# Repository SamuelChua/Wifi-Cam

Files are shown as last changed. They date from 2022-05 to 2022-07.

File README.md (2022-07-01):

# Building a 'Wifi-Seeing' Camera

## Description

In this project, I used a software defined radio (SDR) along with a directional Yagi antenna to scan and detect Wifi signals, overlaying it on top of a normal camera
image in order to give directional information of signal sources (possibly through
walls!). Overall, I controlled and manipulated both the radio and camera with DSP and arduino control of a servo motor for the antenna. With this application, I'm able to display the spatial awareness of Wifi signals. 

WhatsApp Image 2022-06-30 at 9 37 27 AM (1)

## Table of Contents 
- Hardware/Software Tools used
- Programs/Files
- Running the program
- Video Demonstration
- Ideas I experimented with along the way
- Concluding Remarks 

## Hardware/Software Tools Used
### USRP Software Defined Radio 
The USRP B205 Mini-i is a SDR designed by Ettus Research which has a Frequency range: 70 MHz – 6 GHz and up to 56 MHz of instantaneous Bandwidth. Using SDR technologies can allow me to easily configure to the requirements I'm looking to detect Wifi signals


### Yagi Antenna
The 2.4GHz Yagi Antenna is a directional antenna which has a good front-to-back ratio of 16dB to minimise unwanted signals. 


Here are some links to the datasheet of the antenna 

https://www.farnell.com/datasheets/1580319.pdf

### Servo Motor
Despite its small size, the servo motor has a peak stall torque of 1.5kg.cm which is sufficient to rotate the antenna (300g) given certain support of the antenna. Similarly, here are some links to the datasheet of the servo motor

https://sg.element14.com/multicomp-pro/mp-708-0001/servo-motor-180deg/dp/3359813?CMP=i-55c5-00001621
https://www.farnell.com/datasheets/2914226.pdf

### GNURadio 
GNU Radio is a free & open-source software development toolkit that provides signal processing blocks to implement software radios. I ran it mainly with Python 

GNURadio was installed via http://www.gcndevelopment.com/gnuradio/downloads.htm on Windows, specifically GNURadio V3.8.2.0-win64 for my project. 

### Arduino
Arduino is an open-source tool for electronics projects which consists of the microcontroller and an IDE to run and upload code to the physical Arduino code. 

### Reimage Package

Credits to my mentor, Gabriel. I can save the trouble of repeatedly running np.abs(d) and the lag to generate a graph
https://github.com/icyveins7/reimage

## Programs/Files
Webcam
- Controlling the USB Webcam

Arduino
- Will send Arduino list of angles via serial communication from Python to Arduino

Master
- Master Program to control the GNURadio, Arduino and Webcam 

Extract
- GNURadio generated script with additional new_main function to access GNURadio 'locally'

Pano
- Generate panorama from the photos taken by webcam

Read_filename
- Data processing of bin file generated from GNURadio to give final heatmap of relative power from Wifi signals + overlaying picture of surrounding

Vert_Hori
- Arduino code to accept the list of angles from Arduino.py, and move the servos to control the vertical and horizontal movement of the antenna via serial communication between Python and Arduino

Sweep/Servo Motor
- Arduino test code to ensure that the servo is working 

Reimage package
- To visualise recorded RF data in IQ samples

3D Prints
- STL and SCAD files for 3D printing
- Infill Density 30-50% depending on application (how dense is the print)
- Made use of MakerBot.Print/GrabCAD Print (Using UPrint SE Plus/Industry Printer in DSO Playground of which those with PRINT extension used GrabCAD Print)

## Running the program
After installing GNURadio, ensure the connnections are made between the servo and Arduino and USRP is plugged into your device. Run master.py in GNURadio command line with the extract.py in the same directory and let the fun begin! 



### GNURadio Flowgraph

There are 2 routes you can use the flowchart

1. Muting the signal via a "Switch" (Used in this project)
By making use GT GUI Chooser with my Multiply Const block, I can change the value of the constant in the GNURadio interacing when running the script, just muting the USRP source by a flick of a switch. 



2. Timed Intervals 
Created a custom embedded python block to record for n seconds then mute the USRP signal for n seconds. The cycle will then continue



### Arduino (Vert_Hori)

The code is designed to split the string of angles arduino.py sends into its horizontal & vertical components and having map the speed to control the movement of the servo 

### read_filename

Below is the illustration of how the mean power values are calculated 
Screenshot 2022-05-19 113415 png-mh

## Video Demonstration

Refer to https://youtu.be/VoVrBwUprhU

## Ideas I experimented with along the way: 

### GNURadio
#### Generating the output bin file:
- Using a selector block and n file sinks as output (Able to get 6 separate readings in 6 bin files but limitation was the version I was using couldn't update to latest selector block with input and output index to swap between different output indices. Additionally, having n sinks to give n separate readings wouldn't be sustainable to keep adding file sink blocks in GNURadio)



- Using custom python blocks to swap sinks (Swap File Sink & Custom File Sink)
Couldn't come to fruition, nonetheless might need more than 1 file sink as it may not be possible to reuse the same file sink after swapping to null sink
Note that Custom File Sink is a Hier Block




- Getting the GNURadio to record the data using stream tags (stream.grc/tagged file sink.grc). Had trouble to generate tags and getting the flowchart to recognise these tags/bursts to switch the on/off record 

- Getting timed recordings using the 'head' block in GNURadio(extract_nogui.grc). It did work to an extent, as it will turn off the USRP afterwards and not knowing how it can turn on again

## Concluding Remarks 
I thoroughly enjoyed the entire process of figuring out how open source frameworks like GNURadio and Arduino work, building my own 'WiFi-seeing' camera from scratch independently. I'm most certainly looking forward to exploiting more technologies that touch both hardware and software. Feel free to reach out for any questions!

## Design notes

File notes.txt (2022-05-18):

MasterScript.py

--- multiprocess call gnuradioscript.py (default off)

open gnuradioscript, webcam, arduino (current progress)		

start while 1:
	master tell arduino.py to send one command
	arduino.py (send one command to arduino)
	arduino move (send msg to master that it's done)
	master send command to webcam to take pic and gnuradio to record for 5s
	webcam take pic, multiprocess turn on gnuradio 
	multiprocess turn off gnuradio (send msg to master that it's done)
	master tell arduino.py to send next command
	arduino.py (send one command to arduino)
	arduino move 
	....
	arduino last angle (0:180&1:180)

horizontal movement (with gear plus secure stick to wooden board)
mount webcam onto antenna

import os 
from multiprocessing import Pool
from threading import Thread
processes = ('extract.py', 'webcam.py', 'pano.py', 'read_filename.py', 'Vert_Hori.ino' )
def run_processes(process):
	os.system('python {}'.format(process))
pool = Pool(processes=3)
pool.map(run_process, processes)

def read_data(queue_, should_stop):
    while not should_stop.is_set():
        # calculate/get cX, cY, angle
        queue_.put((cX, cY, angle))
        # sleep 30ms

def send_to_ardunio(queue_, should_stop):
    while not should_stop.is_set():
        data = queue_.get()
        cX, cY, angle = data
        # update ardunio

def tell_when_to_stop(should_stop):
    # detect when to stop, and set the Event. For example, we'll wait for 10 seconds and then ask all to stop
    time.sleep(10)
    should_stop.set()

queue_ = Queue()
should_stop = Event()

thread_stop_decider = Thread(target=tell_when_to_stop, args=(should_stop,))
thread_read = Thread(target=read_data, args=(queue_, should_stop))
thread_ardunio = Thread(target=send_to_ardunio, args=(queue_, should_stop))

thread_read.start()
thread_ardunio.start()
thread_stop_decider.start()

try:
    while thread_read.is_alive():
        thread_read.join(1)
except KeyboardInterrupt:
        should_stop.set()
thread_read.join()
thread_ardunio.join()
thread_stop_decider.join()

3D Print Settings
Infill Density 30-50% depending on application, how dense is the print 
Position of print relative to base 

MakerBot.Print/GrabCAD Print (Using UPrint SE Plus/Industry Printer in Playground)

SCAD

Those which have PRINT extension are under GrabCAD Print

1. Customizable cylinder(Small cylinder with hole, orignally meant for the string to be wounded around the nail)
2. Planetary_Gear_Bearing (Initial V1 Bearing)
3. Ball BEaring (V2 Bearing)
4. Gear V1 (Gear on stick)
5. Servo Holder 
6. Spur Gears_10T_18T_final(Gear on stick with 10 and 18 teeth after editing on TinkerCAD with custom Internal Diameter Size)
7. Spur Gears_10T_10M (Original from Thingiverse)
8. Spur Gears_18T_10M (Original from Thingiverse)
9. Pulley_Mount (Pulley for Vertical Movement, original file)
10. Spur Gears_10T_10M_V2 (gear on stick with 10 and 18 teeth with default ID size from 7 and 8)
11. Pulley_Final (Scaled in x and z axis)

 ###### Test.py - Gnuradio Companion generated program file to see and listen to different freqs #######
 ###### epy_block_0.py - Python block to link to USRP for timed commands (using time.sleep()) #######
 ###### stream.py - Use Message Strobe + Stream Tags + Custom Py block to read and print tags to freq hop once after 20s ######
 ###### epy_block_0_read_tag.py - Python block to read stream tags ######

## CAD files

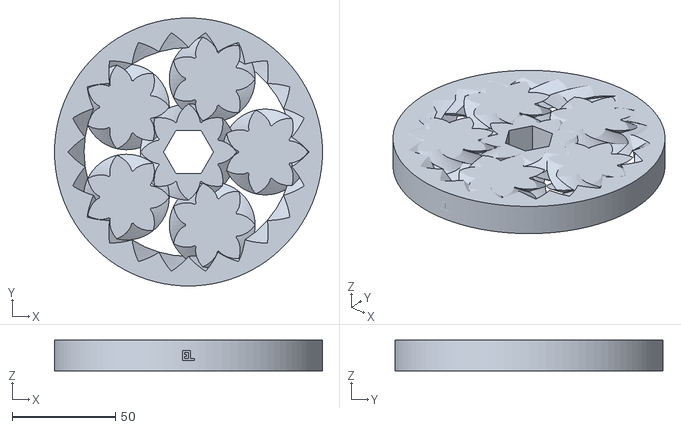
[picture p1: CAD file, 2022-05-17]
3D Prints/Drafts/Planetary_Gear_Bearing.stl
130.0 x 130.0 x 15.0

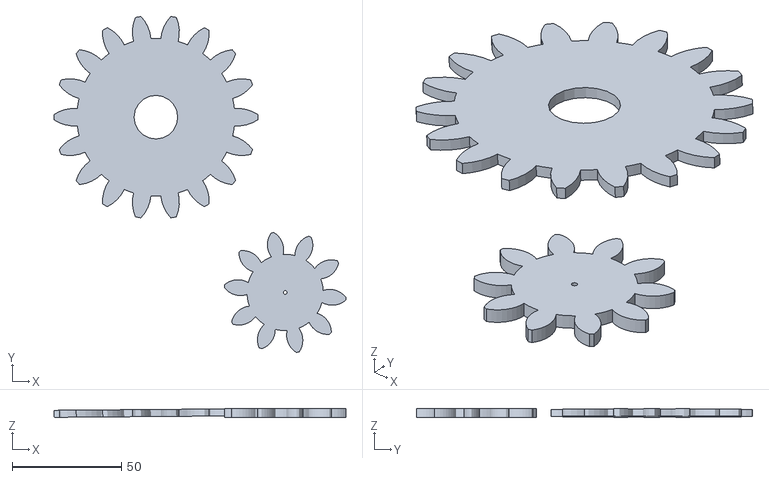
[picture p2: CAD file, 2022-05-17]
3D Prints/Finals Files/Spur Gears_10T_18T_final.stl
133.9 x 154.0 x 4.00

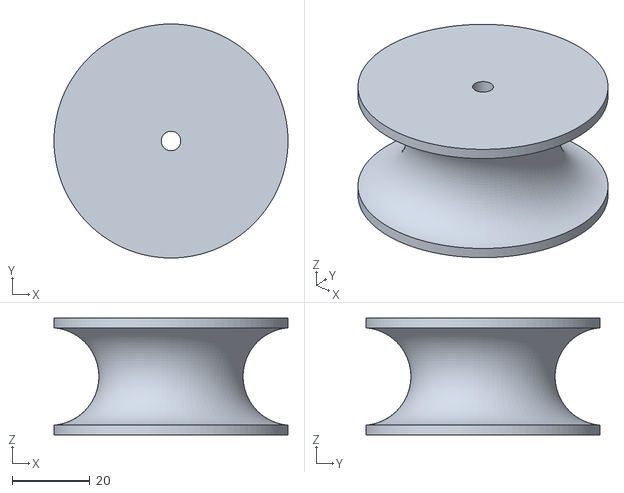
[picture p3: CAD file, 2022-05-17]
3D Prints/Originals/Pulley_Mount.stl
60.0 x 60.0 x 30.0

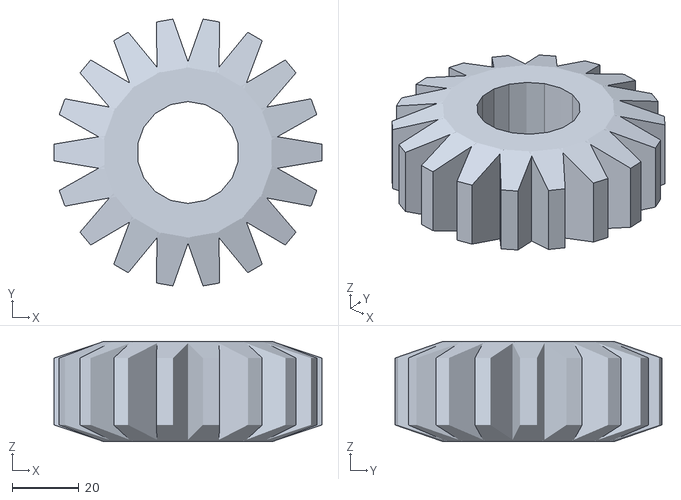
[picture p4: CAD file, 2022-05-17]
3D Prints/Drafts/Gear V1.stl
80.1 x 79.8 x 30.0

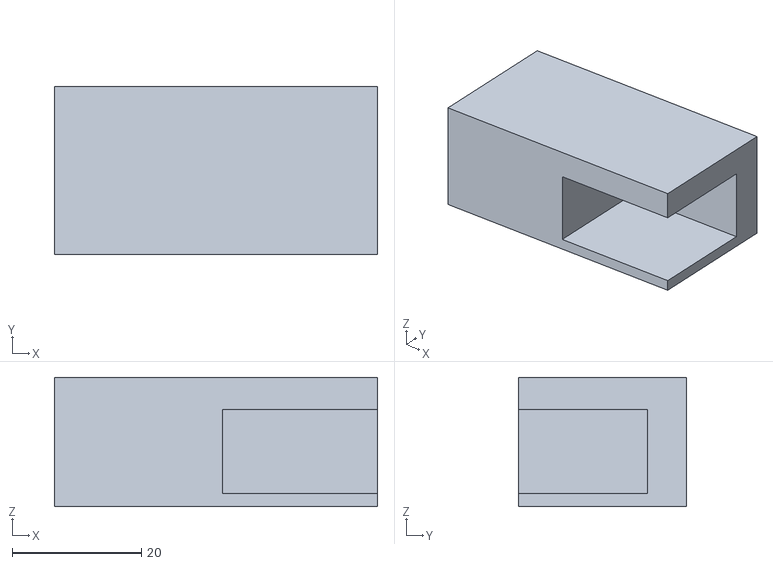
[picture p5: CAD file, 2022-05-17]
3D Prints/Finals Files/Servo Holder.stl
50.0 x 26.0 x 20.0

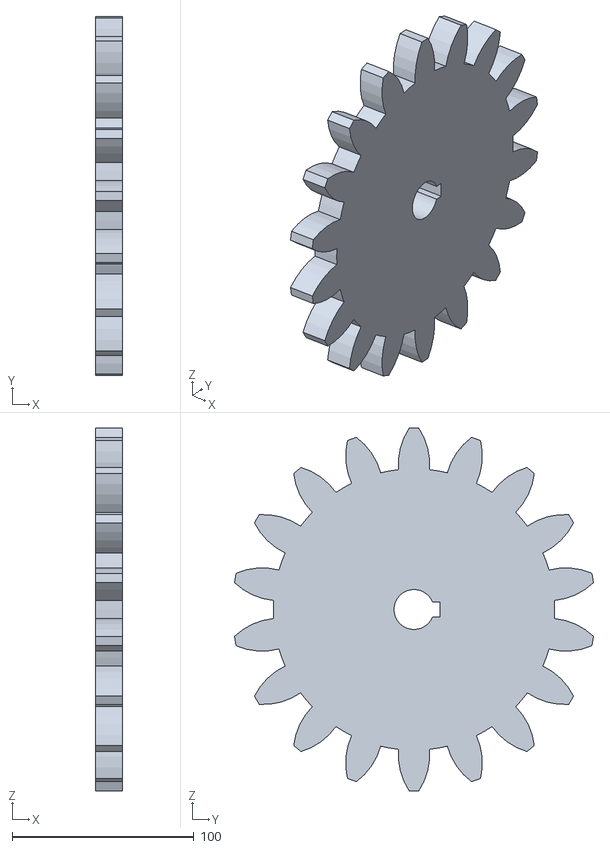
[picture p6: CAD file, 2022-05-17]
3D Prints/Originals/Spur_Gear_10M_18T.STL
15.0 x 197.8 x 199.9

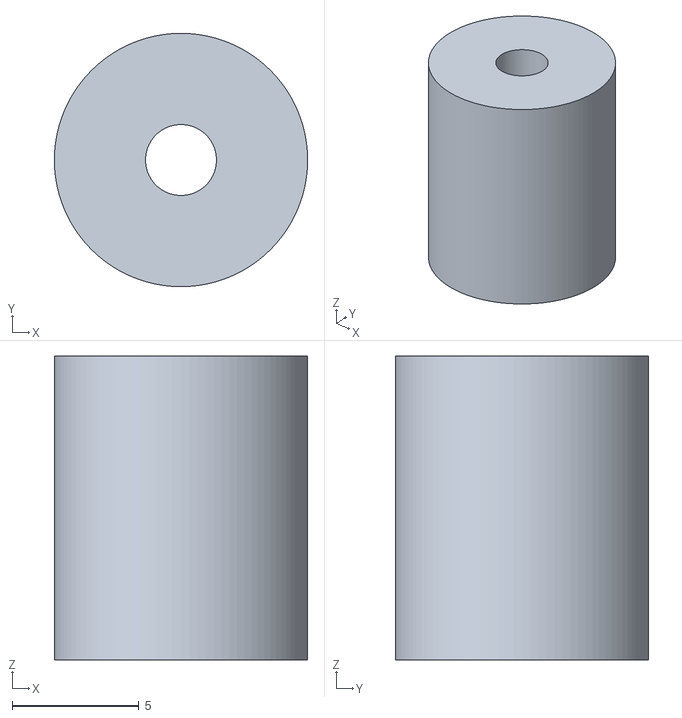
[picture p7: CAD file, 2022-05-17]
3D Prints/Drafts/Customizable_Cylinder.stl
10.0 x 10.0 x 12.0

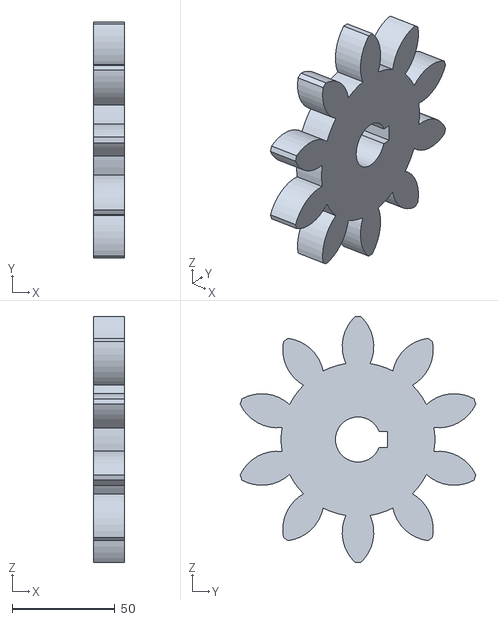
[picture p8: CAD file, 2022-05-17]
3D Prints/Originals/Spur_Gear_10M_10T.STL
15.0 x 114.9 x 120.0

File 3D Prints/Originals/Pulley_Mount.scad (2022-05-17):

// Parametric Pulley

// Which part would you like to print?
printSelection = "Pulley";//[Pulley:Pulley only, Pulley Mount:Pulley Mount only, Both:Both]

// Choose the desired rope diameter in millimeters 
ropeDiameter = 30;//[5:30] 

// Choose a metric bolt size for the shaft
shaftBoltSize = 1;//[4.8:M4, 5.8:M5, 7:M6, 8:M7, 10:M8, 12:M10]

// Choose a metric bolt size for mounting
mountBoltSize = 10;//[4.8:M4, 5.8:M5, 7:M6, 8:M7, 10:M8, 12:M10]

pulleyHeight = ropeDiameter+1;

print_part();

// This module chooses which part to display
module print_part() 
{
	if (printSelection == "Pulley") 
	{
		translate([0,0,pulleyHeight/2]) Pulley();
	} 
	else if (printSelection == "Pulley Mount") 
	{
		translate([0,2*pulleyHeight+5,pulleyHeight+25])rotate([-90,0,0])PulleyMount();
	} 
	else if (printSelection == "Both") 
	{
		both();
	} 
	else 
	{
		both();
	}
}

// This module populates both parts
module both() 
{
	translate([0,0,pulleyHeight/2]) Pulley();
	translate([0,2*pulleyHeight+5,pulleyHeight+25])rotate([-90,0,0])PulleyMount();
}

// The module is the pulley wheel
module Pulley()
{
	
	$fn = 100;
	difference()
	{
		cylinder(r = pulleyHeight, h = pulleyHeight, center = true);
		rotate_extrude(convexity = 10)
        scale([1,1,1])
		translate([pulleyHeight+1, 0, 0]) 
		circle(r = ropeDiameter/2);

		// This is the hole for the shaft
		cylinder(r = shaftBoltSize/2, h = pulleyHeight+1, center = true);
	}
}

// This module is the pulley mount
module PulleyMount()
{
	$fn = 100;
	difference()
	{
		union()
		{
			translate([0, (pulleyHeight+25)/2, 0])
			cube(size = [2*pulleyHeight+25, pulleyHeight+25, pulleyHeight+20], 
					center = true);
			cylinder(r= pulleyHeight+12.5, h = pulleyHeight+20, center = true);
		}
		cube(size  = [2*pulleyHeight+26,2*pulleyHeight+27.5, pulleyHeight+2.5], 
				center = true);

		// This is the hole for the shaft
		cylinder(r = shaftBoltSize/2, h = pulleyHeight+26, center = true);
		
		// These are the holes for mounting
		translate([pulleyHeight/2+5,0,0]) 
		rotate([90,0,0])
		cylinder(r=mountBoltSize/2, h = 1000, center = true);
			
		translate([-pulleyHeight/2-5,0,0]) 
		rotate([90,0,0])
		cylinder(r=mountBoltSize/2, h = 1000, center = true);
		
	}
}

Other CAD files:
3D Prints/Drafts/customizable-cylinder.scad

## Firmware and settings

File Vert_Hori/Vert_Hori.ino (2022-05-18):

  /* Sweep
 by BARRAGAN <http://barraganstudio.com>
 This example code is in the public domain.

 modified 8 Nov 2013
 by Scott Fitzgerald
 https://www.arduino.cc/en/Tutorial/LibraryExamples/Sweep
*/

#include <Servo.h>
#define INPUT_SIZE 30

Servo myservo;  // create servo object to control a servo
Servo myservo1;
//SoftwareSerial mySerial(10, 11); // RX, TX
// twelve servo objects can be created on most boards
int hpos = 0, vpos = 0;// variable to store the servo position
int pos1 = 0; 
int pos2 = 0;
//int datafromUser=0;
String inByte;
  

void setup() {
  // put your setup code here, to run once:
  Serial.begin(9600);
  //mySerial.begin(9600); 
  
  myservo.attach(9);  // attaches the servo on pin 9 to the servo object
  myservo1.attach(4);  // attaches the servo on pin 4 to the servo object
  myservo.write(0); //Remember to end servo position at 0
  myservo1.write(0);
  myservo.detach();  // attaches the servo on pin 9 to the servo object
  myservo1.detach();
  
  
}


void moveTo1 (int position, int speed){
  unsigned int mapSpeed = map(speed, 0,30,30,0);
  if (position > vpos){
    for (vpos = pos1; vpos <= position; vpos +=1){
      myservo1.write(vpos);
      pos1 = vpos;
      delay(mapSpeed);
    } 
  }
  else{
    for (vpos = pos1; vpos >= position; vpos -=1){
      myservo1.write(vpos);
      pos1 = vpos;
      delay(mapSpeed);
  }
}
  
}

void vert_only(int position){
  myservo1.attach(4);
//  while (Serial.available()){
//    myservo1.attach(4);
//    inByte = Serial.readString();
// 
  Serial.print("Servo in vert position: ");
  Serial.println(String(position));  
//    position = inByte.toInt();
  
  moveTo1(position, 1);
  myservo1.detach();
}


void moveTo (int position, int speed){
  unsigned int mapSpeed = map(speed, 0,30,30,0);
  if (position > hpos){
    for (hpos = pos2; hpos <= position; hpos +=1){
      myservo.write(hpos);
      pos2 = hpos;
      delay(mapSpeed);
    } 
  }
  else{
    for (hpos = pos2; hpos >= position; hpos -=1){
      myservo.write(hpos);
      pos2 = hpos;
      delay(mapSpeed);
  }
}
  
}

void hori(int position){
  
  // put your main code here, to run repeatedly:
  
  myservo.attach(9);
  
  
//  while (Serial.available()){
//    myservo.attach(9);  
//    inByte = Serial.readString();
// 
    Serial.print("Servo in hori position: ");
    Serial.println(String(position));  
//    position = inByte.toInt();
  
  moveTo(position, 1);
  myservo.detach();
}    



//
//void vert(){
//   
//   for (pos2 = 0; pos2 <= 180; pos2 += 1) { // goes from 0 degrees to 180 degrees
//    // in steps of 1 degree
//    myservo1.write(pos2);              // tell servo to go to position in variable 'pos'
//    delay(15);                       // waits 15 ms for the servo to reach the position
//  }
//  for (pos2 = 180; pos2 >= 0; pos2 -= 1) { // goes from 180 degrees to 0 degrees
//    myservo1.write(pos2);              // tell servo to go to position in variable 'pos'
//    delay(15);                       // waits 15 ms for the servo to reach the position
//  }
//  
//}

void loop() { 
  char input[INPUT_SIZE + 1];
  byte size = Serial.readBytes(input, INPUT_SIZE);
// Add the final 0 to end the C string
  input[size] = 0;

// Read each command pair 
  char* command = strtok(input, "&");
  while (command != 0)
  {
    // Split the command in two values
    char* separator = strchr(command, ':');
    if (separator != 0)
    {
        // Actually split the string in 2: replace ':' with 0
        *separator = 0;
        int servoId = atoi(command);
        ++separator;
        int position = atoi(separator);
        
        // Do something with servoId and position
        if (servoId == 0){
          hori(position);
        }
        if (servoId == 1){
          vert_only(position);
        }
        // Find the next command in input string
       command = strtok(0, "&");
    }
  
  //vert()
  }
  
}
  


  
//  datafromUser=Serial.read();
//
//  if(datafromUser == '1') 
//  {
//    for (pos = 0; pos <= 180; pos += 1) { // goes from 0 degrees to 180 degrees
//    // in steps of 1 degree
//      if (datafromUser == '0'){
//        break;
//      }
//      myservo.write(pos);              // tell servo to go to position in variable 'pos'
//      delay(15);                       // waits 15 ms for the servo to reach the position
//  }
//    for (pos = 180; pos >= 0; pos -= 1) { // goes from 180 degrees to 0 degrees
//      myservo.write(pos);              // tell servo to go to position in variable 'pos'
//      delay(15);                       // waits 15 ms for the servo to reach the position
//  } 
//  }
//  else if(datafromUser == '0')
//  {
//    myservo.write(pos);
//  }
//  
//  else{
//    myservo.detach();
//  }
//    
//}

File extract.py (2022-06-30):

#!/usr/bin/env python3
# -*- coding: utf-8 -*-

#
# SPDX-License-Identifier: GPL-3.0
#
# GNU Radio Python Flow Graph
# Title: Extract
# GNU Radio version: v3.8.2.0-57-gd71cd177  

# GNU Radio Generated Script with edits from line 246   

from distutils.version import StrictVersion

if __name__ == '__main__':
    import ctypes
    import sys
    if sys.platform.startswith('linux'):
        try:
            x11 = ctypes.cdll.LoadLibrary('libX11.so')
            x11.XInitThreads()
        except:
            print("Warning: failed to XInitThreads()")

from PyQt5 import Qt
from PyQt5.QtCore import QObject, pyqtSlot
from gnuradio import qtgui
from gnuradio.filter import firdes
import sip
from datetime import datetime
from gnuradio import analog
from gnuradio import blocks
from gnuradio import gr
import sys
import signal
from argparse import ArgumentParser
from gnuradio.eng_arg import eng_float, intx
from gnuradio import eng_notation
from gnuradio import uhd
import time
from gnuradio.qtgui import Range, RangeWidget

from gnuradio import qtgui

class extract(gr.top_block, Qt.QWidget):

    def __init__(self):
        gr.top_block.__init__(self, "Extract")
        Qt.QWidget.__init__(self)
        self.setWindowTitle("Extract")
        qtgui.util.check_set_qss()
        try:
            self.setWindowIcon(Qt.QIcon.fromTheme('gnuradio-grc'))
        except:
            pass
        self.top_scroll_layout = Qt.QVBoxLayout()
        self.setLayout(self.top_scroll_layout)
        self.top_scroll = Qt.QScrollArea()
        self.top_scroll.setFrameStyle(Qt.QFrame.NoFrame)
        self.top_scroll_layout.addWidget(self.top_scroll)
        self.top_scroll.setWidgetResizable(True)
        self.top_widget = Qt.QWidget()
        self.top_scroll.setWidget(self.top_widget)
        self.top_layout = Qt.QVBoxLayout(self.top_widget)
        self.top_grid_layout = Qt.QGridLayout()
        self.top_layout.addLayout(self.top_grid_layout)

        self.settings = Qt.QSettings("GNU Radio", "extract")

        try:
            if StrictVersion(Qt.qVersion()) < StrictVersion("5.0.0"):
                self.restoreGeometry(self.settings.value("geometry").toByteArray())
            else:
                self.restoreGeometry(self.settings.value("geometry"))
        except:
            pass

        ##################################################
        # Variables
        ##################################################
        self.prefix = prefix = 'C:\\Users\\intern\\Documents\\GitHub\\Wifi-Cam\\signal_data\\filename'
        self.tuning = tuning = 2.422e9
        self.time = time = prefix + datetime.now().strftime("%H.%M.%S")
        self.samp_rate = samp_rate = 4e5
        self.duration = duration = 5
        self.Switch = Switch = 0

        ##################################################
        # Blocks
        ##################################################
        self._tuning_range = Range(70e6, 3e9, 2e6, 2.422e9, 200)
        self._tuning_win = RangeWidget(self._tuning_range, self.set_tuning, 'tuning', "counter_slider", float)
        self.top_grid_layout.addWidget(self._tuning_win)
        # Create the options list
        self._Switch_options = (0, 1, )
        # Create the labels list
        self._Switch_labels = ('Off', 'On', )
        # Create the combo box
        self._Switch_tool_bar = Qt.QToolBar(self)
        self._Switch_tool_bar.addWidget(Qt.QLabel('Switch' + ": "))
        self._Switch_combo_box = Qt.QComboBox()
        self._Switch_tool_bar.addWidget(self._Switch_combo_box)
        for _label in self._Switch_labels: self._Switch_combo_box.addItem(_label)
        self._Switch_callback = lambda i: Qt.QMetaObject.invokeMethod(self._Switch_combo_box, "setCurrentIndex", Qt.Q_ARG("int", self._Switch_options.index(i)))
        self._Switch_callback(self.Switch)
        self._Switch_combo_box.currentIndexChanged.connect(
            lambda i: self.set_Switch(self._Switch_options[i]))
        # Create the radio buttons
        self.top_grid_layout.addWidget(self._Switch_tool_bar)
        self.uhd_usrp_source_0 = uhd.usrp_source(
            ",".join(("", "")),
            uhd.stream_args(
                cpu_format="fc32",
                args='',
                channels=list(range(0,1)),
            ),
        )
        self.uhd_usrp_source_0.set_center_freq(tuning, 0)
        self.uhd_usrp_source_0.set_rx_agc(False, 0)
        self.uhd_usrp_source_0.set_gain(70, 0)
        self.uhd_usrp_source_0.set_antenna('RX2', 0)
        self.uhd_usrp_source_0.set_bandwidth(samp_rate, 0)
        self.uhd_usrp_source_0.set_samp_rate(samp_rate)
        self.uhd_usrp_source_0.set_time_unknown_pps(uhd.time_spec())
        self.qtgui_sink_x_0 = qtgui.sink_c(
            1024, #fftsize
            firdes.WIN_BLACKMAN_hARRIS, #wintype
            tuning, #fc
            samp_rate, #bw
            "", #name
            True, #plotfreq
            True, #plotwaterfall
            True, #plottime
            True #plotconst
        )
        self.qtgui_sink_x_0.set_update_time(1.0/10)
        self._qtgui_sink_x_0_win = sip.wrapinstance(self.qtgui_sink_x_0.pyqwidget(), Qt.QWidget)

        self.qtgui_sink_x_0.enable_rf_freq(True)

        self.top_grid_layout.addWidget(self._qtgui_sink_x_0_win)
        self.blocks_multiply_const_vxx_0 = blocks.multiply_const_cc(Switch)
        self.blocks_file_sink_0 = blocks.file_sink(gr.sizeof_gr_complex*1, time, False)
        self.blocks_file_sink_0.set_unbuffered(False)
        self.analog_pwr_squelch_xx_0 = analog.pwr_squelch_cc(-140, 1e-4, 0, False)



        ##################################################
        # Connections
        ##################################################
        self.connect((self.analog_pwr_squelch_xx_0, 0), (self.blocks_file_sink_0, 0))
        self.connect((self.analog_pwr_squelch_xx_0, 0), (self.qtgui_sink_x_0, 0))
        self.connect((self.blocks_multiply_const_vxx_0, 0), (self.analog_pwr_squelch_xx_0, 0))
        self.connect((self.uhd_usrp_source_0, 0), (self.blocks_multiply_const_vxx_0, 0))


    def closeEvent(self, event):
        self.settings = Qt.QSettings("GNU Radio", "extract")
        self.settings.setValue("geometry", self.saveGeometry())
        event.accept()

    def get_prefix(self):
        return self.prefix

    def set_prefix(self, prefix):
        self.prefix = prefix
        self.set_time(self.prefix + datetime.now().strftime("%H.%M.%S"))

    def get_tuning(self):
        return self.tuning

    def set_tuning(self, tuning):
        self.tuning = tuning
        self.qtgui_sink_x_0.set_frequency_range(self.tuning, self.samp_rate)
        self.uhd_usrp_source_0.set_center_freq(self.tuning, 0)

    def get_time(self):
        return self.time

    def set_time(self, time):
        self.time = time
        self.blocks_file_sink_0.open(self.time)

    def get_samp_rate(self):
        return self.samp_rate
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

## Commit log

2022-03-04 Used Micro Servo to turn 180 with speed control
2022-03-04 Base code for Joystick control of Micro Servo
2022-03-07 Added custom function to toggle recording using on/off push button, produced binary IQ raw data but timestamp doesn't work
    [extract.py]
2022-03-14 Added Push Button function but not sure if working
2022-05-09 Master Program to control arduino and gnuradio
    Master program for arduino and gnuradio, need some cleaning up of redundant functions like changeSwitch, mp.event, mp.condition
2022-05-17 Servo Holder STL
    To hold servo motors in place
    [Servo Holder.stl]
2022-05-17 Files from Thingiverse
    https://www.thingiverse.com/thing:2813245
    [Spur_Gear_10M_10T.STL, Spur_Gear_10M_18T.STL]
2022-05-17 Gears on stick for horizontal movement
    [Spur Gears_10T_18T_final.stl]
2022-05-17 Pulley for vertical movement scaled in x and z axis
2022-05-17 Original file for pulley using SCAD
    [Pulley_Mount.scad, Pulley_Mount.stl]
2022-05-17 2 gears of 10 & 18 teeth
2022-05-17 Small cylinder with hole
    Originally meant for the string to be wounded around the nail for vertical movement
    [Customizable_Cylinder.stl, customizable-cylinder.scad]
2022-05-17 Plastic ball bearing
    Later switched to metal bearing
2022-05-17 1st version of gear
    [Gear V1.stl]
2022-05-17 1st version of bearing using planetary gears
    [Planetary_Gear_Bearing.stl]
2022-05-17 Python program to send commands to Arduino Uno
2022-05-17 Added simple binary reader, calculate mean of n readings & print heatmap
2022-05-17 Added option for user input of servo angle
2022-05-17 Option of using switch on/off or timed intervals
2022-05-17 Cleaned up redundant functions, linked to read_filename to determine axis of heatmap
2022-05-18 fixed "function has no attribute" error
    [master.py]
2022-05-18 Dumping ground for code
2022-05-18 Did not use Stepper Motor in project
2022-05-18 Added additional arduino file to test if servo is working
2022-05-18 Main code uploaded to Arduino to turn servos
2022-06-30 Pano no longer in use as images generated are lopsided
    [pano.py]
